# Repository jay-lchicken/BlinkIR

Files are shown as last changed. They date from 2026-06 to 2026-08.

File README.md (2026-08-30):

## To the previous review
"Hey! Cool project, but it needs to be polished a bit before it can be approved, you can organise the files in speicific folders such as PCB/etc. I also believe this can be cost optimized a lot, please take a look at the docs, right now you can get 54$ worth of grant for the project but your BOM is totalling to 3 times of that, you should save costs on the PCBA, by trying to fit all components on one side, using components only from standard libray, getting only 2 pcba rather than 5, etc."

I will reorganise the files into the folders. However, for the cost optimisation, it is not really possible for this project since the LEDs cannot be on the same side as the phototransistor and thus require a double-sided assembly. Getting only 2pcba rather than 5 only saves $10, so I may as well go with 5. I can pay the extra price that the grant cannot cover. also, some components are really big and cannot be on the same side as phototransistor else it would hit the ground, like the 47uf electrolytic capacitor

### The sample code in the repository basically lights up the corresponding LEDs when the phototransistor detects black. The code also uses button 1 to start the program
# Introduction

I created this project when I saw a super fast line tracing robot. I thought about what was needed and since one of the most crucial components for a line tracing robot is the IR Array Sensor, I decided

What if I can make one of the most responsive and feature-packed IR Sensor ever made.

# Description

I took inspiration from the Pololu QTR-8A. It is equipped with 8 IR emitters and 8 IR Recievers (or maybe phototransistors, I'm not sure).

I did the same and put it into my PCB with 8 IR emitters and 8 phototransistors that uses the voltage divider rule to give users the reading.

Doing this, I realised that the project ended up being just a normal IR Array sensor. I thought hard about how I could make it unique. Personally, I have building robots since young and it came to my mind
that if I can solve all the problems I previously had with a robot by implementing the solution in the PCB, it would be great! 

I usually hate using the Serial Monitor when debugging my hardware code, so I decided to add 8 SK6812 Neopixel indicator lights to the pcb, one for each IR Sensor but on the other side of the PCB.
The user can have full control of the LEDs but for me, I want to be able to change the light depending on what the phototransistor detects. This helps make debugging with the IR array sensor a lot easier.
When testing line tracking, I can also easily see how I can fine tune the robot when line tracking by looking at the LEDs which I can program to light up when it detects a certain black that meets the treshold value

Competitive robots require a Start/Stop button which I normally use jumper wires to implement. However, these wires often get loose and prevent the robot from starting. Since I am already desiging a PCB, I might as well put some buttons

Image of the pcb with buttons and the neopixel

Bottom side of the PCB with the IR emitter an phototransistor

# How it all fits together
I added a Buck-Boost converter which allow you to put 3.3V to 12V into the IR array sensor. Then, the converter will convert it to 5V which is the proper operating voltage for the circuit.
There are 8 pins which the users can tap into individually with their microcontroller to read the phototransistor readings. There are also another 3 pins. Two for the two INPUT_PULLUP Buttons as well as one for contorlling the daisy chained SK6812 Neopixel LEDs.
Lastly, there are another 3 pins for Vin, GND and turning on the IR Emitter

I decided to go with 4.7K resistors for the phototransistors, this helps balance between the noise and speed for the IR Array Sensor
# Some Schematic Images
Schematic P1
Schematic P2
PCB

# BOM 



## 🧾 Components

| Part Number | Selected By | Qty | Cost |
|---|---|-----|---|
| FRC1206F4700TS | System | 15 | $0.08 |
| 0402WGF3300TCE | System | 20 | $0.02 |
| CL10A106KP8NNNC | System | 40 | $0.36 |
| 0603WAF1003T5E | System | 40 | $0.03 |
| NTD3528I7 | System | 44 | $1.66 |
| TPS63070RNMT | System | 5 | $8.42 |
| CL31A226KAHNNNE | System | 14 | $2.50 |
| 0805W8F4702T5E | System | 20 | $0.04 |
| 0805W8F5233T5E | System | 20 | $0.05 |
| KT-0603W | System | 20 | $0.24 |
| RVT102470M0505 | Customer | 20 | $0.58 |
| SK6812 | System | 42 | $3.73 |
| 0805W8F4701T5E | System | 46 | $0.10 |
| 2.54-1×3P# | Customer | 12 | $0.29 |
| MPT0603GT | System | 44 | $1.83 |
| CL05B104K05NNNC | System | 40 | $0.05 |
| 1206W4F1002T5E | System | 15 | $0.09 |
| CMI060808U22RK7 | System | 20 | $0.34 |
| JSM2302 | Customer | 15 | $0.30 |
| CL10A105KB8NNNC | System | 20 | $0.22 |
| KMR221GLFS | System | 10 | $5.31 |
| 0603WAF470J5E | System | 40 | $0.08 |

## 💰 Cost Summary

| Category | Amount |
|---|---|
| Merchandise Total (incl. assembly) | $153.07 |
| Shipping (Estimated) | $8.85 |
| **Subtotal** | **$161.92** |

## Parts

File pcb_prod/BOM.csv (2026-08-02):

Part Detail | Selected by | Top Designator | Bottom Designator | Qty | Ext. Price | LCSC Link
FRC1206F4700TS | System |  |  | 15.0 | $0.08 | https://www.lcsc.com/search?q=FRC1206F4700TS
0402WGF3300TCE | System |  |  | 20.0 | $0.02 | https://www.lcsc.com/search?q=0402WGF3300TCE
CL10A106KP8NNNC | System |  |  | 40.0 | $0.36 | https://www.lcsc.com/search?q=CL10A106KP8NNNC
0603WAF1003T5E | System |  |  | 40.0 | $0.03 | https://www.lcsc.com/search?q=0603WAF1003T5E
NTD3528I7 | System |  |  | 44.0 | $1.66 | https://www.lcsc.com/search?q=NTD3528I7
TPS63070RNMT | System |  |  | 5.0 | $8.42 | https://www.lcsc.com/search?q=TPS63070RNMT
CL31A226KAHNNNE | System |  |  | 14.0 | $2.50 | https://www.lcsc.com/search?q=CL31A226KAHNNNE
0805W8F4702T5E | System |  |  | 20.0 | $0.04 | https://www.lcsc.com/search?q=0805W8F4702T5E
0805W8F5233T5E | System |  |  | 20.0 | $0.05 | https://www.lcsc.com/search?q=0805W8F5233T5E
KT-0603W | System |  |  | 20.0 | $0.24 | https://www.lcsc.com/search?q=KT-0603W
RVT102470M0505 | Customer |  |  | 20.0 | $0.58 | https://www.lcsc.com/search?q=RVT102470M0505
SK6812 | System |  |  | 42.0 | $3.73 | https://www.lcsc.com/search?q=SK6812
0805W8F4701T5E | System |  |  | 46.0 | $0.10 | https://www.lcsc.com/search?q=0805W8F4701T5E
2.54-1×3P# | Customer |  |  | 12.0 | $0.29 | https://www.lcsc.com/search?q=2.54-1%C3%973P%23
MPT0603GT | System |  |  | 44.0 | $1.83 | https://www.lcsc.com/search?q=MPT0603GT
CL05B104K05NNNC | System |  |  | 40.0 | $0.05 | https://www.lcsc.com/search?q=CL05B104K05NNNC
1206W4F1002T5E | System |  |  | 15.0 | $0.09 | https://www.lcsc.com/search?q=1206W4F1002T5E
CMI060808U22RK7 | System |  |  | 20.0 | $0.34 | https://www.lcsc.com/search?q=CMI060808U22RK7
JSM2302 | Customer |  |  | 15.0 | $0.30 | https://www.lcsc.com/search?q=JSM2302
CL10A105KB8NNNC | System |  |  | 20.0 | $0.22 | https://www.lcsc.com/search?q=CL10A105KB8NNNC
KMR221GLFS | System |  |  | 10.0 | $5.31 | https://www.lcsc.com/search?q=KMR221GLFS
0603WAF470J5E | System |  |  | 40.0 | $0.08 | https://www.lcsc.com/search?q=0603WAF470J5E
 |  |  |  |  |  | NA
 |  |  |  |  |  | NA
 |  |  |  |  |  | NA
Merchandise Total (Inclusive of assembly services) |  |  |  |  |  | NA
153.07 |  |  |  |  |  | NA
Shipping Estimated |  |  |  |  |  | NA
$8.85 |  |  |  |  |  | NA
Subtotal |  |  |  |  |  | NA
$161.92 |  |  |  |  |  | NA

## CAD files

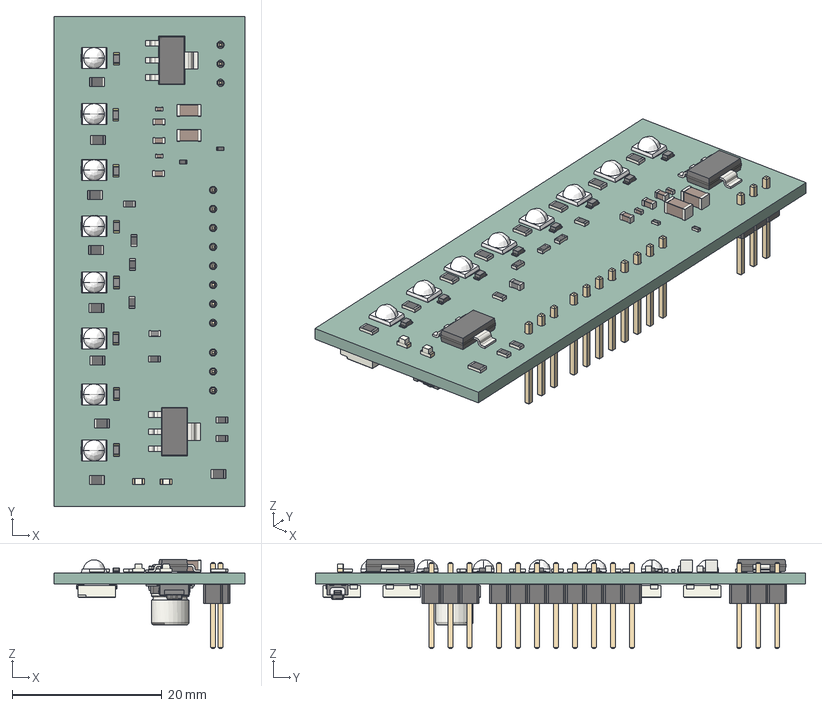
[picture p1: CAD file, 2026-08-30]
pcb_prod/BlinkIR.step
25.5 x 65.6 x 11.9 mm
R_0805_2012Metric x 10
LED-SMD_L3.5-W2.8-FD-1 x 8
L_0603_1608Metric
OPTO-SMD_L1.7-W0.8 x 8
R_0603_1608Metric x 8
R_0402_1005Metric x 2
C_1206_3216Metric x 2
LED_0603_1608Metric x 2
C_0603_1608Metric x 4
C_0402_1005Metric x 3
SOT-223 x 2
LED_SK6812_PLCC4_5.0x5.0mm_P3.2mm x 8
PinHeader_1x03_P2.54mm_Vertical x 2
PinHeader_1x08_P2.54mm_Vertical
R_1206_3216Metric x 2
TPS63070RNMT
KEY-SMD_5P-L4.2-W2.8-H1.9-LS4.6-P1.6 x 2
CP_Elec_5x5.4
BlinkIR_PCB

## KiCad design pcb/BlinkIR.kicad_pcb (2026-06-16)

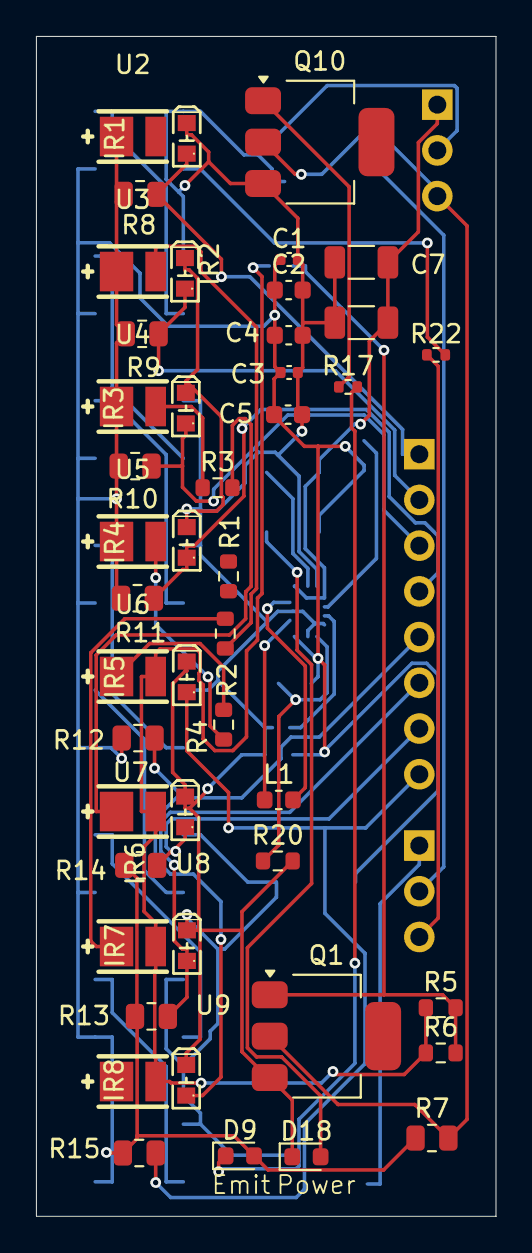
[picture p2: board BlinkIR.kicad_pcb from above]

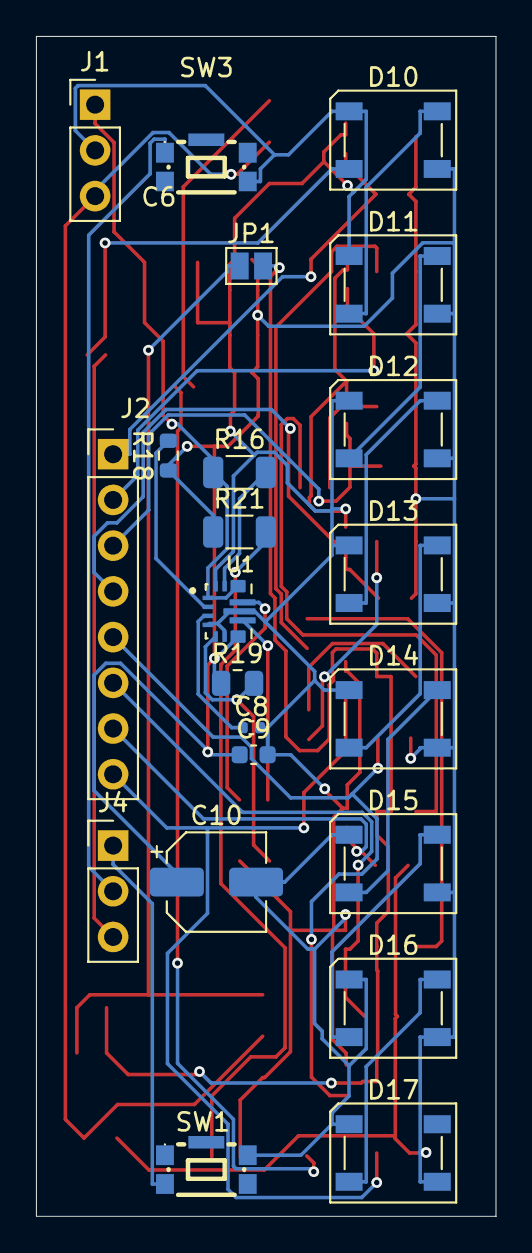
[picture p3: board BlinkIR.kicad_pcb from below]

Board: 2 copper layers, 25.5 x 65.6 mm, 68 parts (22 on the bottom side), 42 nets.

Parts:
C1, C3: 0.1uF; C_0402_1005Metric
C2, C4: 1.0uF; C_0603_1608Metric
C5, C9: 10uF; C_0603_1608Metric
C6, C7: 22uF; C_1206_3216Metric
C8: 100nF; C_0402_1005Metric
C10: 47uF; CP_Elec_5x5.4
D9, D18: LED; LED_0603_1608Metric
D10, D11, D12, D13, D14, D15, D16, D17: SK6812; LED_SK6812_PLCC4_5.0x5.0mm_P3.2mm
IR1, IR2, IR3, IR4, IR5, IR6, IR7, IR8: MPT60363T; OPTO-SMD_L1.7-W0.8
J1, J4: Conn_01x03_Pin; PinHeader_1x03_P2.54mm_Vertical
J2: Conn_01x08_Pin; PinHeader_1x08_P2.54mm_Vertical
JP1: SolderJumper_2_Open; SolderJumper-2_P1.3mm_Open_Pad1.0x1.5mm
L1: 2.2uH; L_0603_1608Metric
Q1, Q10: NMOS; SOT-223
R1, R2, R3, R4, R5, R6: 47; R_0603_1608Metric
R7: 47k; R_0805_2012Metric
R8, R9, R10, R11, R12, R13, R14, R15: 4.7k; R_0805_2012Metric
R16: 10k; R_1206_3216Metric
R17, R22: 330; R_0402_1005Metric
R18, R20: 100k; R_0603_1608Metric
R19: 523k; R_0805_2012Metric
R21: 470; R_1206_3216Metric
SW1, SW3: KMR221GLFS; KEY-SMD_KMR2XXGXXX
U1: TPS63070RNMT; VREG_TPS63070RNMT
U2, U3, U4, U5, U6, U7, U8, U9: NTD3528I7; LED-SMD_L3.5-W2.8-FD-1

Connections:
/IR1: IR1.1 (C), J2.1, R8.2
/IR2: IR2.1 (C), J2.2, R9.2
/IR3: IR3.1 (C), J2.3, R10.2
/IR4: IR4.1 (C), J2.4, R11.2
/IR5: IR8.1 (C), J2.5, R12.2
/IR6: IR7.1 (C), J2.6, R13.2
/IR7: IR6.1 (C), J2.7, R14.2
/IR8: IR5.1 (C), J2.8, R15.2
/IR_ON: J1.3, Q1.2 (G), Q10.2 (G), R7.2
GND: C1.2, C2.2, C3.2, C4.2, C5.2, C6.1, C7.1, C8.2, C9.2, C10.2, D10.1 (VSS), D11.1 (VSS), D12.1 (VSS), D13.1 (VSS), D14.1 (VSS), D15.1 (VSS), D16.1 (VSS), D17.1 (VSS), D18.1 (K), IR1.2 (E), IR2.2 (E), IR3.2 (E), IR4.2 (E), IR5.2 (E), IR6.2 (E), IR7.2 (E), IR8.2 (E), J1.2, Q1.3 (S), Q10.3 (S), R20.2, SW1.2, SW3.4, U1.4 (GND), U1.6 (FB2), U1.10 (PGND), U1.15 (VSEL)
unnamed: D9.1 (K), R17.2
unnamed: D10.2 (DIN), R22.2
unnamed: D10.4 (DOUT), D11.2 (DIN)
unnamed: D11.4 (DOUT), D12.2 (DIN)
unnamed: D12.4 (DOUT), D13.2 (DIN)
unnamed: D13.4 (DOUT), D14.2 (DIN)
unnamed: D14.4 (DOUT), D15.2 (DIN)
unnamed: D15.4 (DOUT), D16.2 (DIN)
unnamed: D16.4 (DOUT), D17.2 (DIN)
unnamed: D18.2 (A), R21.2
unnamed: J4.1, SW1.3
unnamed: J4.2, SW3.1
unnamed: J4.3, R22.1
unnamed: JP1.1 (A), Q1.1 (D), R5.2, R6.2
unnamed: JP1.2 (B), R5.1, R6.1, U6.2, U7.2, U8.2, U9.2
unnamed: Q10.1 (D), R17.1
unnamed: R1.1, U2.2
unnamed: R1.2, U9.1
unnamed: R2.1, U3.2
unnamed: R2.2, U8.1
unnamed: R3.1, U4.2
unnamed: R3.2, U7.1
unnamed: R4.1, U5.2
unnamed: R4.2, U6.1
unnamed: R16.2, U1.14 (EN)
unnamed: R19.2, R20.1, U1.5 (FB)
unnamed: L1.2, U1.11 (L1)
unnamed: L1.1, U1.9 (L2)
unnamed: R18.2, U1.2 (PG)
unnamed: C8.1, U1.3 (VAUX)
VCC: C1.1, C2.1, C3.1, C4.1, C5.1, C9.1, C10.1, D9.2 (A), D10.3 (VDD), D11.3 (VDD), D12.3 (VDD), D13.3 (VDD), D14.3 (VDD), D15.3 (VDD), D16.3 (VDD), D17.3 (VDD), R7.1, R8.1, R9.1, R10.1, R11.1, R12.1, R13.1, R14.1, R15.1, R18.1, R19.1, R21.1, U1.7_8 (VOUT), U2.1, U3.1, U4.1, U5.1
Vin: C6.2, C7.2, J1.1, R16.1, U1.1 (PS/SYNC), U1.12_13 (VIN)

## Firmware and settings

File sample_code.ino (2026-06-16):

#include <Adafruit_NeoPixel.h>
#define LED_PIN     4
#define LED_COUNT   8
Adafruit_NeoPixel strip(LED_COUNT, LED_PIN, NEO_RGBW + NEO_KHZ800);

void setup() {
  pinMode(A1, INPUT);
  pinMode(A2, INPUT);
  pinMode(A3, INPUT);
  pinMode(A4, INPUT);
  pinMode(A5, INPUT);
  pinMode(A6, INPUT);
  pinMode(A7, INPUT);
  pinMode(A8, INPUT);
  pinMode(1,INPUT_PULLUP);
  pinMode(2, INPUT_PULLUP);
  pinMode(3, OUTPUT);
  digitalWrite(3, HIGH); //Ensure IR Emmitter is always on
  while (digitalRead(1) == 1){
    //wait until button one is pressed
  }
  strip.begin();
  strip.show();
  strip.setBrightness(128);


}

void loop() {
  int v1 = analogRead(A1);
  int v2 = analogRead(A2);
  int v3 = analogRead(A3);
  int v4 = analogRead(A4);
  int v5 = analogRead(A5);
  int v6 = analogRead(A6);
  int v7 = analogRead(A7);
  int v8 = analogRead(A8);
  if (v1 > 500) {
    strip.setPixelColor(0, strip.Color(255, 0, 0, 0));
  }
  if (v2 > 500) {
    strip.setPixelColor(1, strip.Color(255, 0, 0, 0));
  }
  if (v3 > 500) {
    strip.setPixelColor(2, strip.Color(255, 0, 0, 0));
  }
  if (v4 > 500) {
    strip.setPixelColor(3, strip.Color(255, 0, 0, 0));
  }
  if (v5 > 500) {
    strip.setPixelColor(5, strip.Color(255, 0, 0, 0)); 
  }
  if (v6 > 500) {
    strip.setPixelColor(6, strip.Color(255, 0, 0, 0)); 
  }
  if (v7 > 500) {
    strip.setPixelColor(7, strip.Color(255, 0, 0, 0));
  }
  if (v8 > 500) {
    strip.setPixelColor(8, strip.Color(255, 0, 0, 0)); 
  }

  

}
